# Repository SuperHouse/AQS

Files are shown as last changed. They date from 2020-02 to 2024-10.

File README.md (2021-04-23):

Air Quality Sensor
==================

Build a DIY Air Quality Sensor to monitor the condition of the air in
your home or office, with options for measuring airborne particulate
matter, temperature, humidity, barometric pressure, and volatile
organic compounds.

This project is documented in an ongoing video series on SuperHouse:

* [DIY Air Quality Sensor, part 1: “Basic” version](https://www.superhouse.tv/38-diy-air-quality-sensor-part-1-basic-model/)
* [DIY Air Quality Sensor, part 2: “Display” version](https://www.superhouse.tv/39-diy-air-quality-sensor-part-2-display-version/)
* [DIY Air Quality Sensor, part 3: source code walkthrough](https://www.superhouse.tv/40-diy-air-quality-sensor-part-3-software/)

There are 3 different versions of this project:

 * The "Basic" version which requires only a Wemos D1 Mini and a
   Plantower PMS5003 laser particulate matter sensor.
 * The "Display" version which adds a 128x32 OLED display to the
   Basic version.
 * The "Pro" version which is based on a fully custom PCB with an ESP32
   MCU, a Plantower PMS7003 sensor, a Bosch BME680 environmental
   sensor, and a 240x240 colour LCD.

Measurements can be shown locally if a display is fitted, and can also
be reported to MQTT over WiFi so that data can be accessed by a home
automation system or external database.

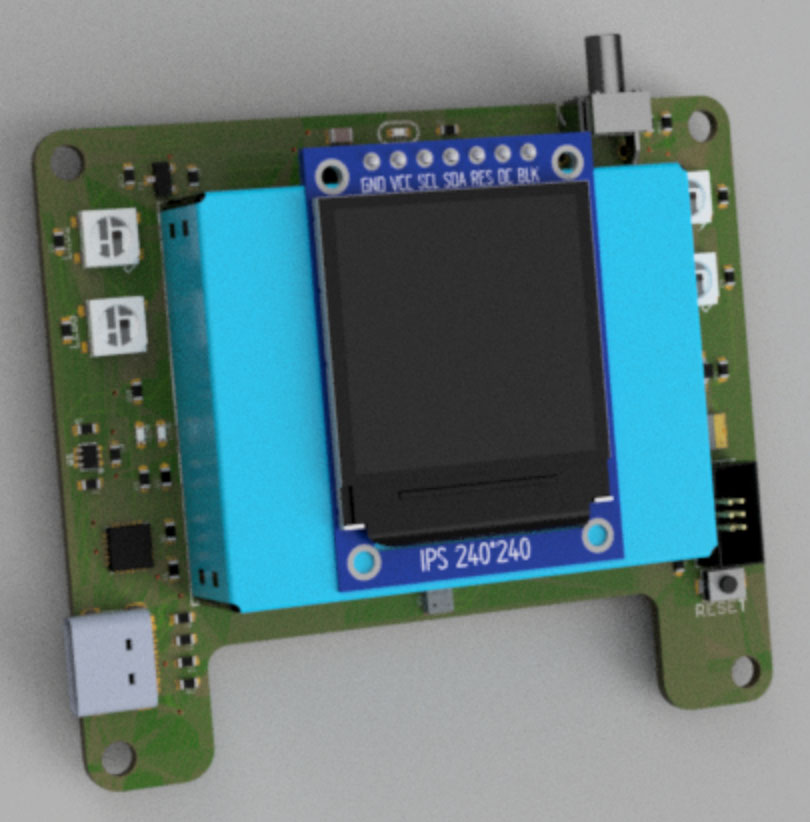
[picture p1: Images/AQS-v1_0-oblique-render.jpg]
Air Quality Sensor PCB


"Basic" and "Display" version features:

 * PMS5003 particulate matter sensor
 * ESP8266 processor with WiFi
 * Micro-USB connection for power or reflashing
 * 3D-printable case

"Pro" version features:

 * PMS7003 particulate matter sensor
 * BME680 VOC sensor
 * ESP32 processor with WiFi and Bluetooth
 * USB-C connection for power or reflashing
 * 3D-printable case

More information is available at:

  https://www.superhouse.tv/aqs

Hardware
--------
The "Hardware" directory contains the PCB design as an EAGLE project.

Firmware
--------
The "Firmware" directory contains example firmware as an Arduino
project.

Enclosure
---------
The "Enclosure" directory contains STLs for a case that can be
3D-printed.

The two halves of the case should be printed with the flat face down to
the printer bed.

The case can be held shut by M3 bolts.

Credits
-------
 * Jonathan Oxer <jon@oxer.com.au>

License
-------
Copyright 2020-2021 SuperHouse Automation Pty Ltd  www.superhouse.tv  

The hardware portion of this project is licensed under the TAPR Open
Hardware License (www.tapr.org/OHL). The "license" folder within this
repository contains a copy of this license in plain text format.

The software portion of this project is licensed under the Simplified
BSD License. The "licence" folder within this project contains a
copy of this license in plain text format.

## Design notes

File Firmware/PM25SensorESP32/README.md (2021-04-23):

"Pro" version Particulate Matter Sensor firmware
=================================================

NOTE: This version of the firmware is for the "Pro" version of the
SuperHouse Air Quality Sensor project. It does not work on the "Basic"
and "Display" version of the project.

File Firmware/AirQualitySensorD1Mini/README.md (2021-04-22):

"Basic" & "Display" Air Quality Sensor firmware for D1 Mini
============================================================

NOTE: This version of the firmware is for the "Basic" and "Display"
versions of the SuperHouse Air Quality Sensor project. It does not
work on the "Pro" version of the project.

Read from a Plantower PMS5003 particulate matter sensor using a Wemos D1
Mini (or other ESP8266-based board) and report the values to an MQTT
broker and show them on a 128x32 OLED display.

The mode button and OLED are optional. You can build this device with
nothing but a PMS5003 and a D1 Mini, and it will work just fine.

On startup, the device reads its own ESP8266 chip ID and uses this as the
basis for its MQTT topics and client ID, to ensure that they will be
unique for each device.

It displays this ID on the OLED display so you can read it off the
display if you have one installed. In case you don't, it also reports
the ID via the serial console at 9600bps, and publishes a startup
message to the topic "events" including its own ID. You can watch that
topic while the device is booting to see what ID it reports.

This ID is then used to generate topics for it to report its readings.
The topics take the following form, with its unique ID substituted:

 * tele/d9616f/PM1
 * tele/d9616f/PM2.5
 * tele/d9616f/PM10
 * tele/d9616f/PPD0.3
 * tele/d9616f/PPD0.5
 * ...etc

The values are also reported in a combined format as JSON, in the same
structure used by Tasmota, at a topic similar to:

 * tele/d9616f/SENSOR

If you install the OLED and the mode button, you can use the button to
toggle the display between different screens. The first screen shows the
most recent readings in micrograms per cubic meter. The second screen
shows the most recent readings in particles per deciliter. The third
screen shows network information including the MQTT ID, IP address, WiFi
SSID, WiFi connection status, and uptime.

Dependencies
------------

These dependencies can all be fulfilled in the Arduino IDE using
"Sketch -> Include Library -> Manage Libraries..."

 * GFX library by Adafruit https://github.com/adafruit/Adafruit-GFX-Library
 * SSD1306 library by Adafruit https://github.com/adafruit/Adafruit_SSD1306
 * PubSubClient library by Nick O'Leary https://pubsubclient.knolleary.net

It also uses a version of Mariusz Kacki's "PMS" library that was forked by
SwapBap. You do not need to install this library separately, because it's
included in the project.

Connections
-----------

For particulate matter sensor:
 * PMS5003 pin 1 (VCC) to D1 Mini "5V" pin
 * PMS5003 pin 2 (GND) to D1 Mini "GND" pin
 * PMS5003 pin 4 (RX) to D1 Mini "D8" pin
 * PMS5003 pin 5 (TX) to D1 Mini "D4" pin

For mode button:
 * Button connected between D1 Mini "D7" pin (GPIO13) and GND

For 128x32 I2C OLED:
 * OLED VCC to D1 Mini 3.3V
 * OLED GND to D1 Mini GND
 * OLED SCL to D1 Mini "D1" pin
 * OLED SDA to D1 Mini "D2" pin

To do
-----

 * 

Credits
-------

Written by Jonathan Oxer for www.superhouse.tv  
https://github.com/superhouse/AQS

Inspired by https://github.com/SwapBap/WemosDustSensor

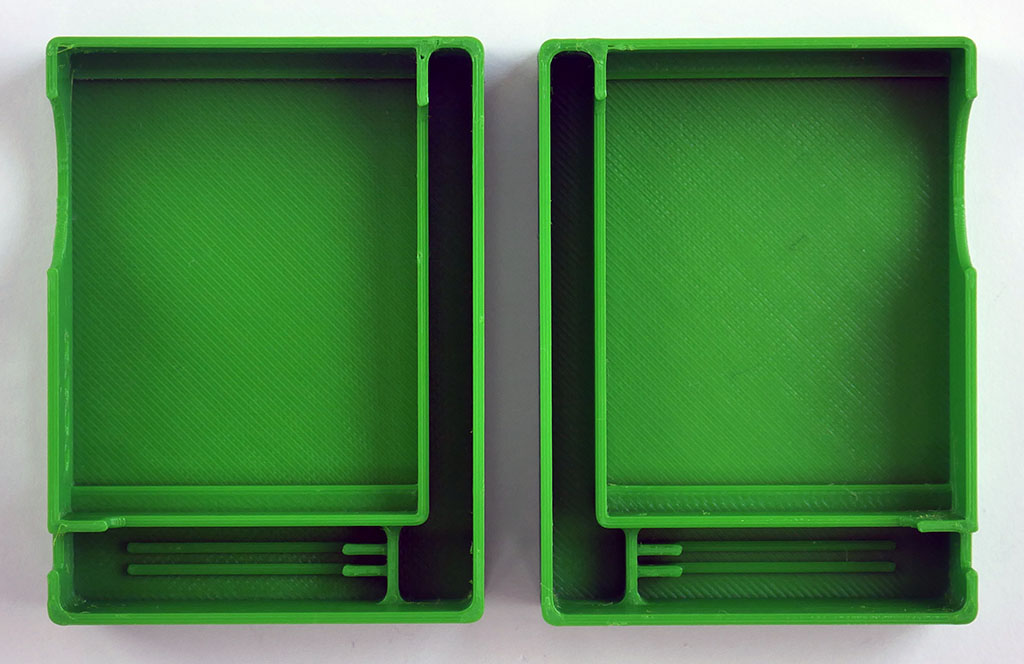
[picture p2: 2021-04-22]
Images/AQSBCASE-v1_0-green-top.jpg

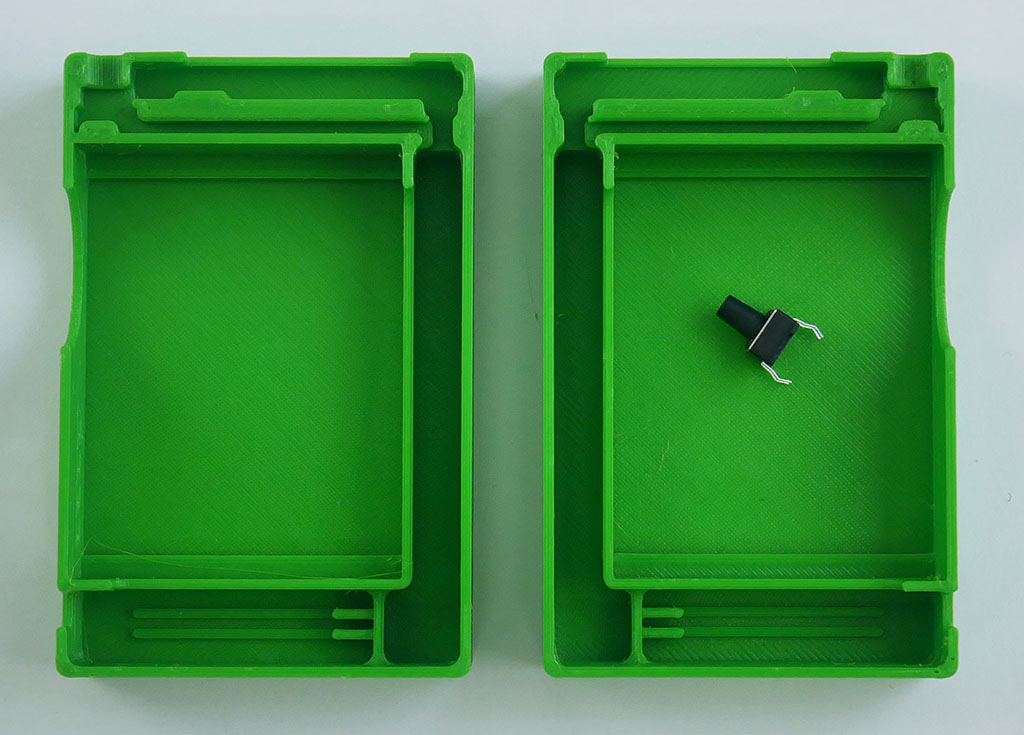
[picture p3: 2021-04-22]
Images/AQSDCASE-v1_0-green-top.jpg

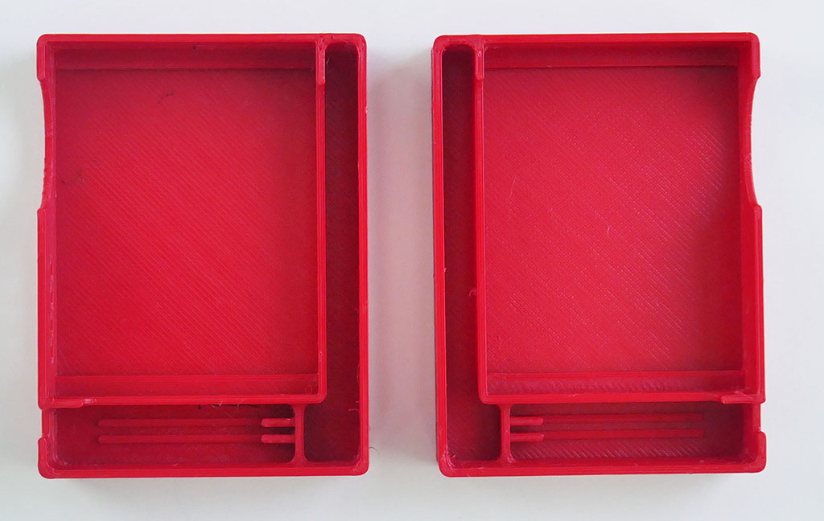
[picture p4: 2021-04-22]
Images/AQSBCASE-v1_0-red-top.jpg

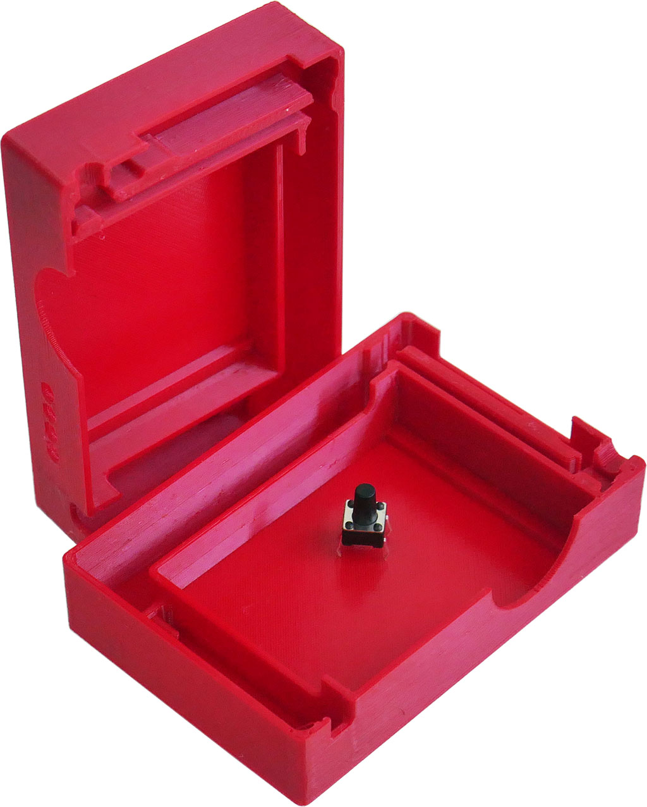
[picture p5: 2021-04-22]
Images/AQSDCASE-v1_0-red-oblique.jpg

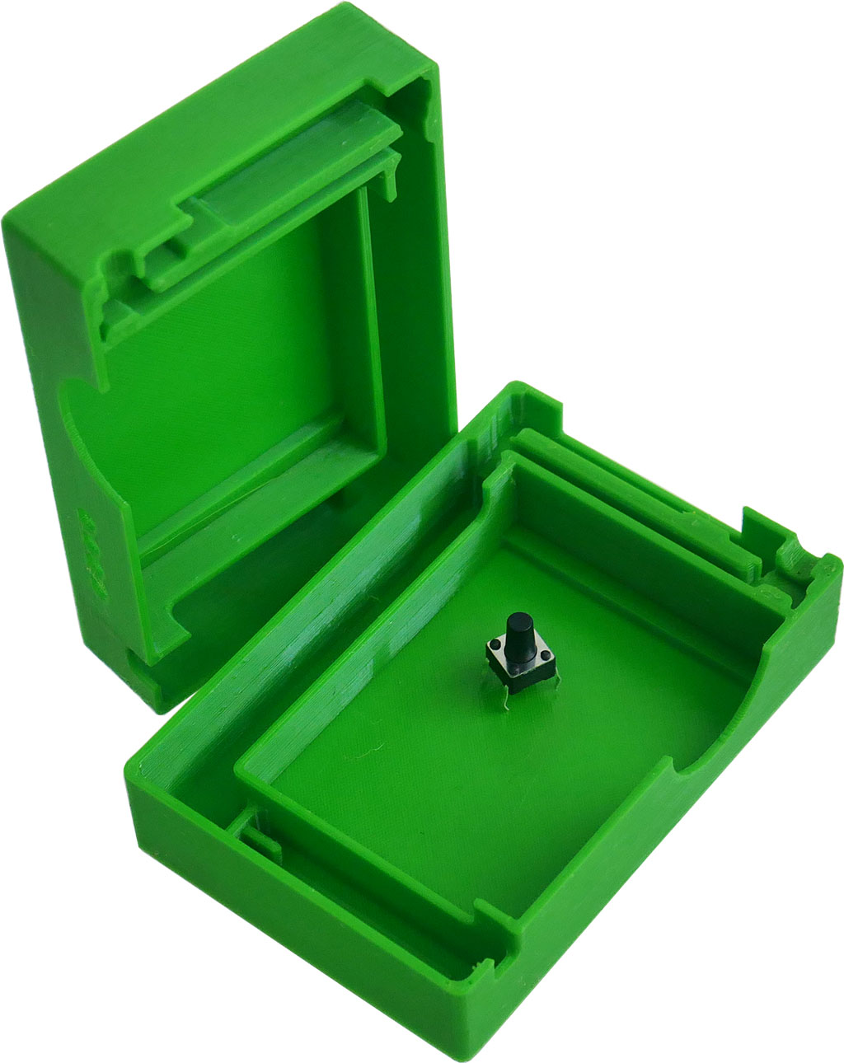
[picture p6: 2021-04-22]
Images/AQSDCASE-v1_0-green-oblique.jpg

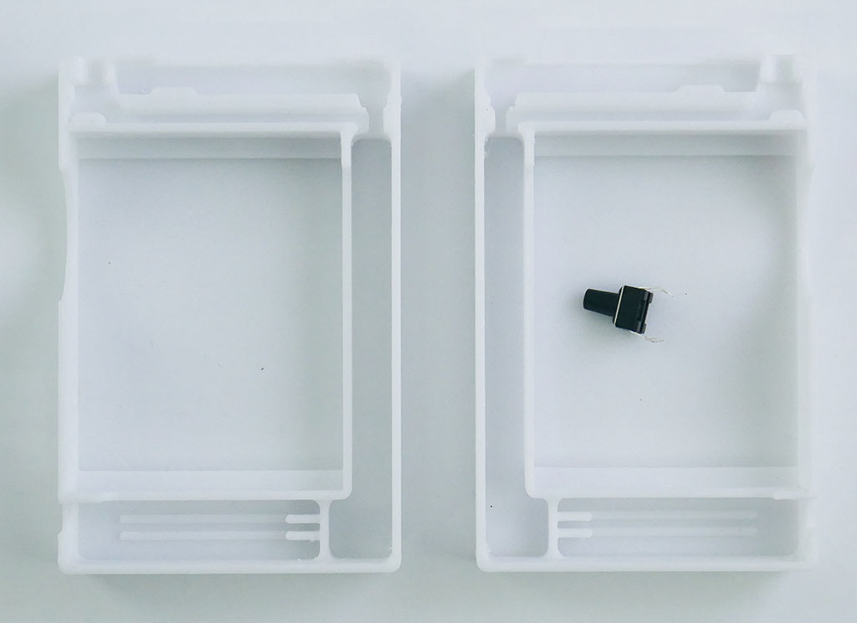
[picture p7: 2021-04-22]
Images/AQSDCASE-v1_0-white-top.jpg

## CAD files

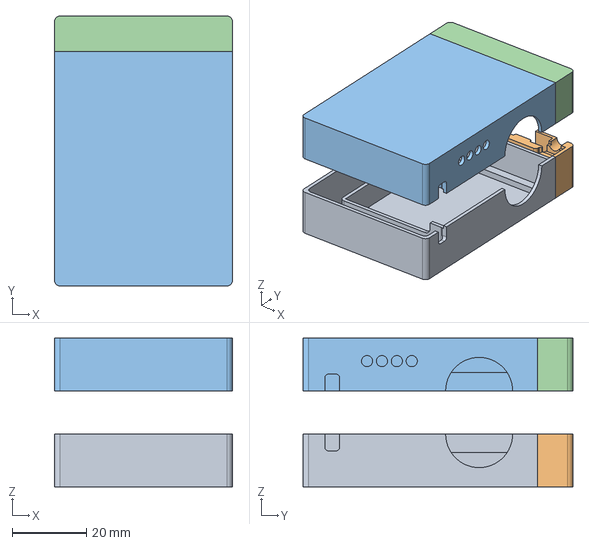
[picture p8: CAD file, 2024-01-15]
Enclosure/AQS-Display-Case-v16.step
47.8 x 72.5 x 40.0 mm

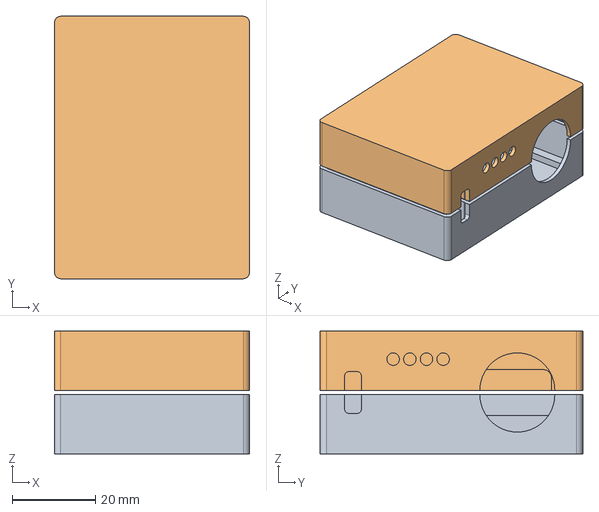
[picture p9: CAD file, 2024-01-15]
Enclosure/AQS-Simple-Case-v5.step
46.8 x 63.0 x 29.4 mm

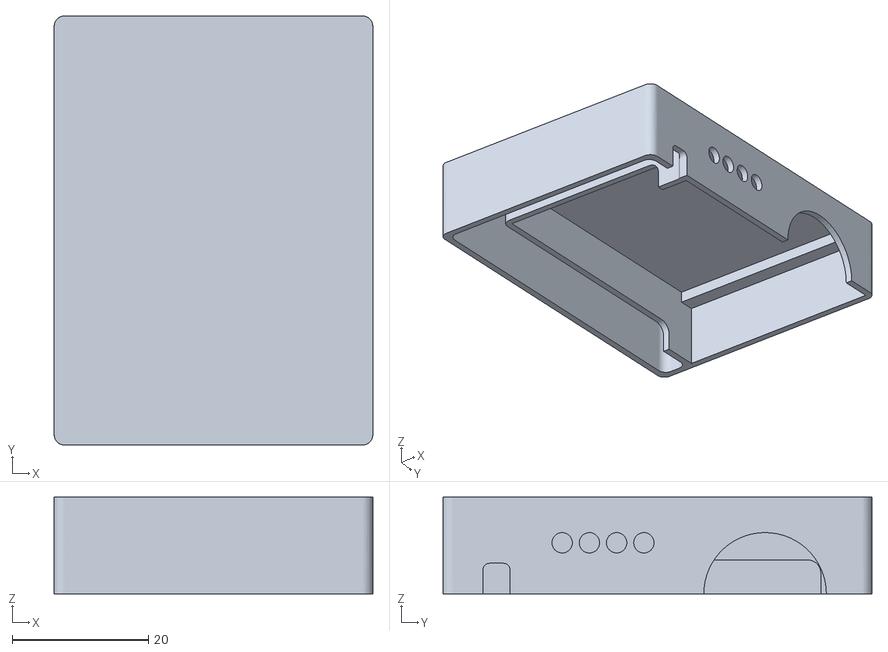
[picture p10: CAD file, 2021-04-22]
Enclosure/AQS-Basic-Case-1_2mm-v1-top.stl
46.8 x 63.0 x 14.2

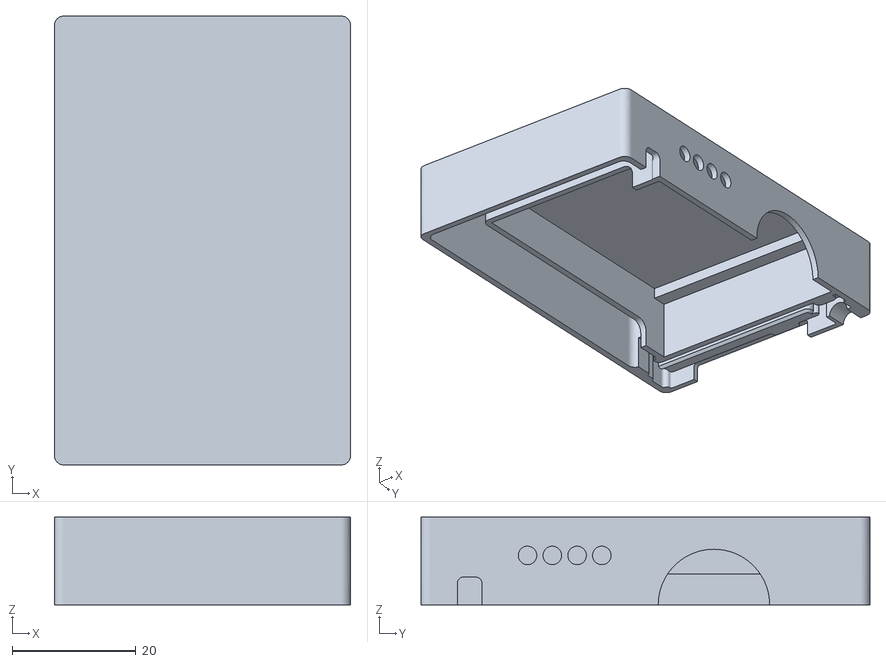
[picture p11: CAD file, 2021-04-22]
Enclosure/AQS-Display-Case-1_2mm-v1-top.stl
47.8 x 72.5 x 14.2

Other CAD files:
Enclosure/AQS-Basic-Case-1_6mm-v1-top.stl
Enclosure/AQS-Display-Case-1_6mm-v1-bottom.stl
Enclosure/AQS-Display-Case-1_6mm-v1-top.stl
Enclosure/AQS-Basic-Case-1_6mm-v1-bottom.stl
Enclosure/AQS-Display-Case-1_2mm-v1-bottom.stl
Enclosure/AQS-Basic-Case-1_2mm-v1-bottom.stl
Enclosure/AQS-Simple-Case-v5.f3d

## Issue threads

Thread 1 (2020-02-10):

The URL specified for more information returns a 404

KathyReid, 2020-02-10:
Hi Jon,
This project looks super exciting, and I'd really like to buy one of these boards from you.
The page http://www.superhouse.tv/aqs is returning a 404

```
kathyreid@kathyreid-zenbook-ux533fd:~$ wget http://www.superhouse.tv/aqs
--2020-02-11 10:33:06--  http://www.superhouse.tv/aqs
Resolving www.superhouse.tv (www.superhouse.tv)... 23.239.0.84
Connecting to www.superhouse.tv (www.superhouse.tv)|23.239.0.84|:80... connected.
HTTP request sent, awaiting response... 301 Moved Permanently
Location: https://www.superhouse.tv/aqs [following]
--2020-02-11 10:33:06--  https://www.superhouse.tv/aqs
Connecting to www.superhouse.tv (www.superhouse.tv)|23.239.0.84|:443... connected.
HTTP request sent, awaiting response... 404 Not Found
2020-02-11 10:33:09 ERROR 404: Not Found.
```

Kind regards,
Kathy

jonoxer, 2020-02-11:
Thanks Kathy! I haven't created the page yet, but I needed to get something onto the silkscreen before I ordered the PCBs. I'll make it soon :-)

KathyReid, 2020-02-11:
Awesomeness <3

jonoxer, 2020-02-11:
Fixed :-)

Closed 2020-02-11.

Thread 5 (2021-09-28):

Mosquito broker issues failures to connect

swissMack, 2021-09-28:
1632836398: New connection from 192.168.1.73 on port 1883.
1632836398: Socket error on client <unknown>, disconnecting.

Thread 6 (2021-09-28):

PMS Tx PIN

swissMack, 2021-09-28:
should this be D6 or D8?
code says D8, website says D6
either way I fail to maintain a connection to my mosquito broker which prevents the code from running as standalone

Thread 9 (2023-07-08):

What happened to parts 4 and 6?

bwims, 2023-07-08:
Hi, what happened to:

Part 4: Recording and reporting Air Quality Sensor data (coming soon)
Part 5: DIY Air Quality Sensor “Pro” version (coming soon)

Coming soon?  It's been 3 years!  :-)

bwims, 2023-09-16:
Bump!

austinscreations, 2023-09-18:
this has been discussed a few times in various livestreams over the years.

1) backend stuff has changed quite a bit over the years that would require a full re-shoot of content to make it useful / relevant
2) life events have happened
3) professional paid work takes precedence. and jons mostly a one man shop with occasional help from his son.

bwims, 2023-09-18:
Fair enough.  In that case, how much effort would there be in coming clean and editing the appropriate information into the blog entries?  I.E. don't raise expectations unnecessarily.  Say.  "Nope.  Forget about any future development. "

Thankfully, ESPhome caters for this device and provides all the extras required.

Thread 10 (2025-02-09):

Stuck on preparing sensors

cruisermattew, 2025-02-09:
The code compiles and is successfully uploaded to the D1 Mini, the screen cycles from the starting menu where the device ID is stated but can't progress past the "preparing sensor and waiting for data" screen. I have used this sensor using Tasmota and received readings so I'm assuming it is an issue with the connection between the sensor and the screen. I am not very knowledgeable in this area so any help would be appreciated.

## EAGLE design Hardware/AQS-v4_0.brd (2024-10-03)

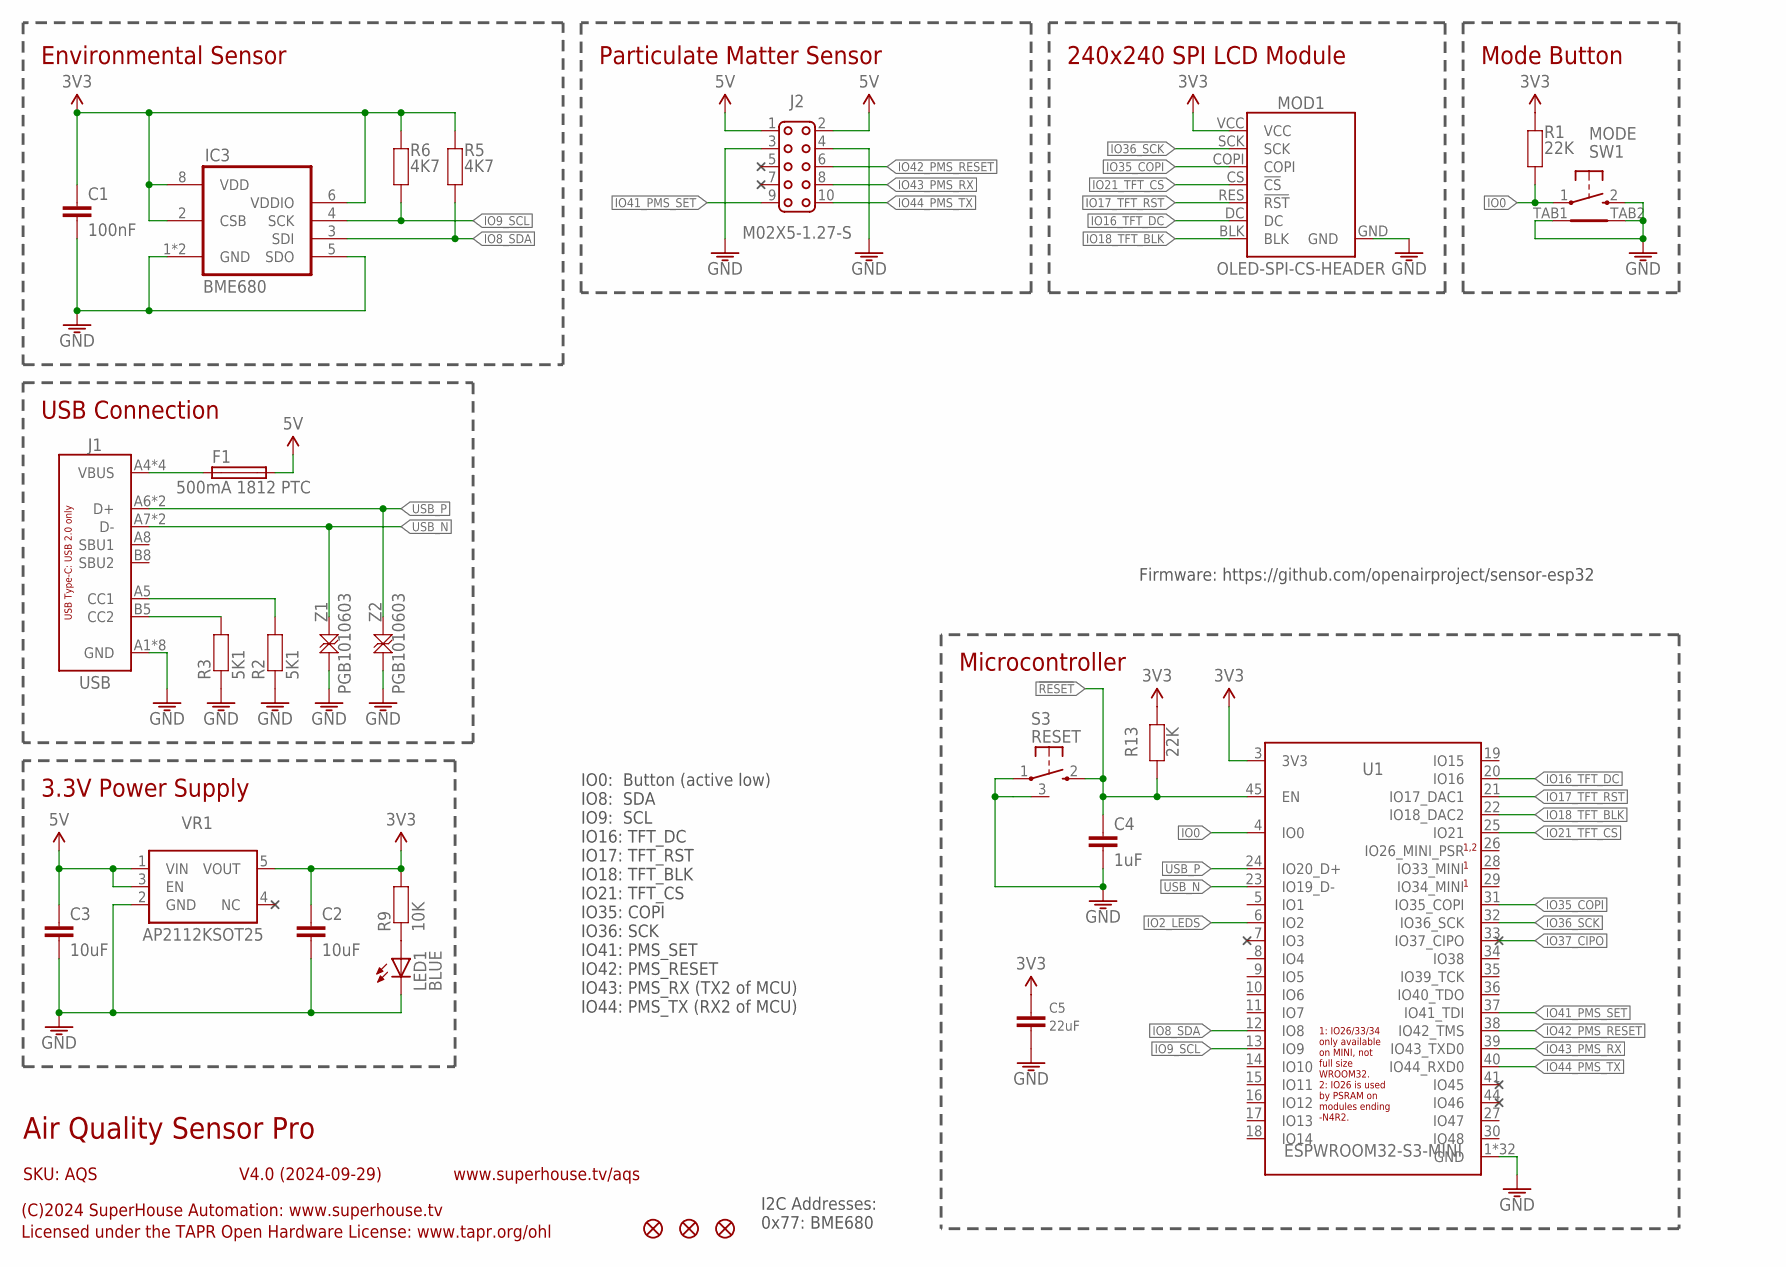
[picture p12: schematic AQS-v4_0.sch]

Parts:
C1: 100nF; C0603
C2, C3: 10uF; C0805
C4: 1uF; C0603
C5: 22uF; C0805
F1: 500mA 1812 PTC; 1206
IC3: BME680
J1: USB; USB-C-VERT
J2: M02X5-1.27-S; 2X05-1.27-S
LED1: BLUE; LED-0603
MOD1: OLED-SPI-CS-HEADER; OLED-240X240-1.54-HEADER
R1, R13: 22K; R0603
R2, R3: 5K1; R0603
R5, R6: 4K7; R0603
R9: 10K; R0603
S3: RESET; TACT-VERT-1TAB
SW1: MODE; TYCO-FSMRAJ
U1: ESPWROOM32-S3-MINI; ESP32-S3-MINI
U$23, U$24, U$25: FIDUCIAL1X2; FIDUCIAL-1X2
VR1: AP2112KSOT25; SOT23-5
Z1, Z2: PGB1010603; TVS0603

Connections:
3.3V: C1.1, C2.1, C5.1, IC3.2 (CSB), IC3.6 (VDDIO), IC3.8 (VDD), MOD1.VCC, R1.2, R5.2, R6.2, R9.2, R13.1, U1.3 (3V3), VR1.5 (VOUT)
5V: C3.1, F1.2, J2.1, J2.2, VR1.1 (VIN), VR1.3 (EN)
!RESET: C4.1, R13.2, S3.2, U1.45 (EN)
GND: C1.2, C2.2, C3.2, C4.2, C5.2, IC3.1 (GND), IC3.5 (SDO), IC3.7 (GND), J1.A1 (GND), J1.A12 (GND), J1.B1 (GND), J1.B12 (GND), J1.FIX1 (GND), J1.FIX2 (GND), J1.FIX3 (GND), J1.FIX4 (GND), J2.3, J2.4, LED1.C, MOD1.GND, R2.1, R3.1, S3.1, S3.3, SW1.2, SW1.TAB1, SW1.TAB2, U1.1 (GND), U1.2 (GND), U1.42 (GND), U1.43 (GND), U1.46 (GND), U1.47 (GND), U1.48 (GND), U1.49 (GND), U1.50 (GND), U1.51 (GND), U1.52 (GND), U1.53 (GND), U1.54 (GND), U1.55 (GND), U1.56 (GND), U1.57 (GND), U1.58 (GND), U1.59 (GND), U1.60 (GND), U1.61 (GND), U1.62 (GND), U1.63 (GND), U1.64 (GND), U1.65 (GND), U1.G1 (GND), U1.G2 (GND), U1.G3 (GND), U1.G4 (GND), U1.G6 (GND), U1.G7 (GND), U1.G8 (GND), U1.G9 (GND), VR1.2 (GND), Z1.1, Z2.1
IO0: R1.1, SW1.1, U1.4 (IO0)
IO2_LEDS: U1.6 (IO2)
IO8_SDA: IC3.3 (SDI), R5.1, U1.12 (IO8)
IO9_SCL: IC3.4 (SCK), R6.1, U1.13 (IO9)
IO16_TFT_DC: MOD1.DC, U1.20 (IO16)
IO17_TFT_RST: MOD1.RES (!RST), U1.21 (IO17_DAC1)
IO18_TFT_BLK: MOD1.BLK, U1.22 (IO18_DAC2)
IO21_TFT_CS: MOD1.CS (!CS), U1.25 (IO21)
IO35_COPI: MOD1.COPI, U1.31 (IO35_COPI)
IO36_SCK: MOD1.SCK, U1.32 (IO36_SCK)
IO37_CIPO: U1.33 (IO37_CIPO)
IO41_PMS_SET: J2.9, U1.37 (IO41_TDI)
IO42_PMS_RESET: J2.6, U1.38 (IO42_TMS)
IO43_PMS_RX: J2.8, U1.39 (IO43_TXD0)
IO44_PMS_TX: J2.10, U1.40 (IO44_RXD0)
IO46: U1.44 (IO46)
unnamed: LED1.A, R9.1
unnamed: F1.1, J1.A4 (VBUS), J1.A9 (VBUS), J1.B4 (VBUS), J1.B9 (VBUS)
unnamed: J1.B5 (CC2), R3.2
unnamed: J1.A5 (CC1), R2.2
USB_N: J1.A7 (D-), J1.B7 (D-), U1.23 (IO19_D-), Z1.2
USB_P: J1.A6 (D+), J1.B6 (D+), U1.24 (IO20_D+), Z2.2

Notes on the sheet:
V4.0 (2024-09-29)
USB Connection
3.3V Power Supply
Microcontroller
I2C Addresses: 0x77: BME680
IO0: Button (active low) IO8: SDA IO9: SCL IO16: TFT_DC IO17: TFT_RST IO18: TFT_BLK IO21: TFT_CS IO35: COPI IO36: SCK IO41: PMS_SET IO42: PMS_RESET IO43: PMS_RX (TX2 of MCU) IO44: PMS_TX (RX2 of MCU)
Air Quality Sensor Pro
SKU: AQS
(C)2024 SuperHouse Automation: www.superhouse.tv
Licensed under the TAPR Open Hardware License: www.tapr.org/ohl
www.superhouse.tv/aqs
Environmental Sensor
240x240 SPI LCD Module
Particulate Matter Sensor
Mode Button
Firmware: https://github.com/openairproject/sensor-esp32

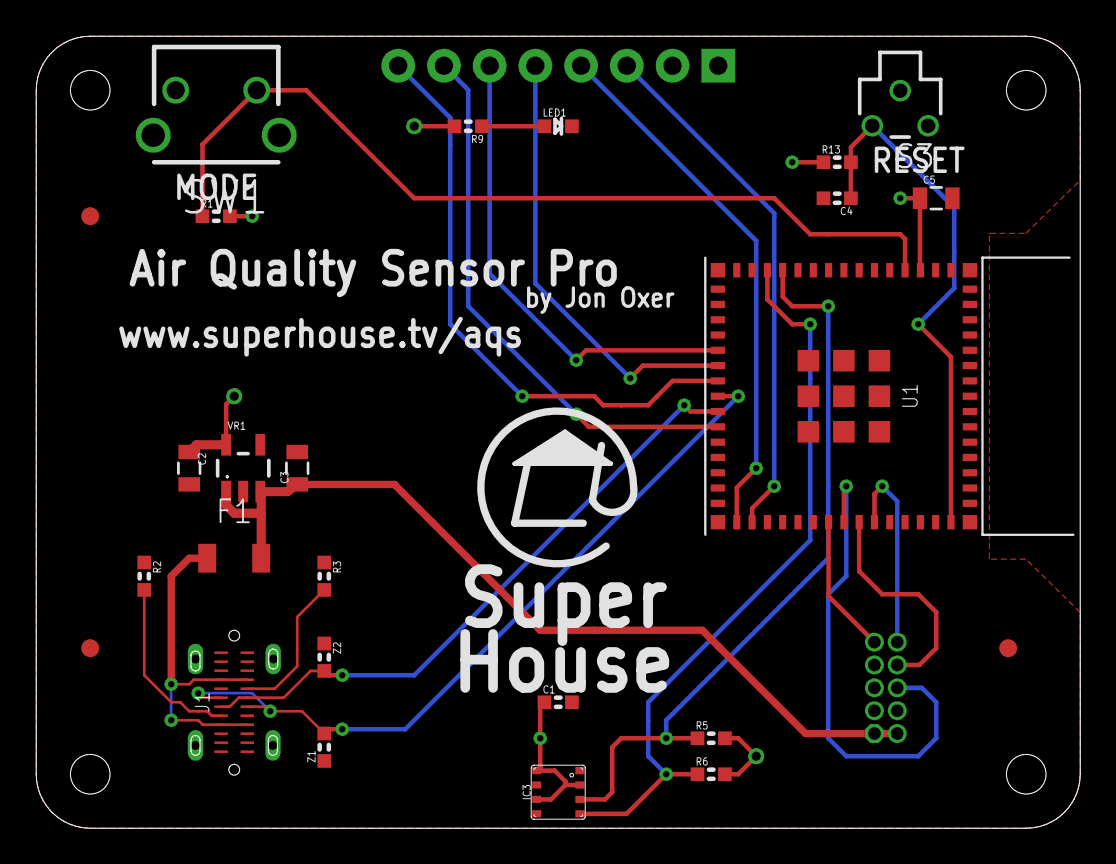
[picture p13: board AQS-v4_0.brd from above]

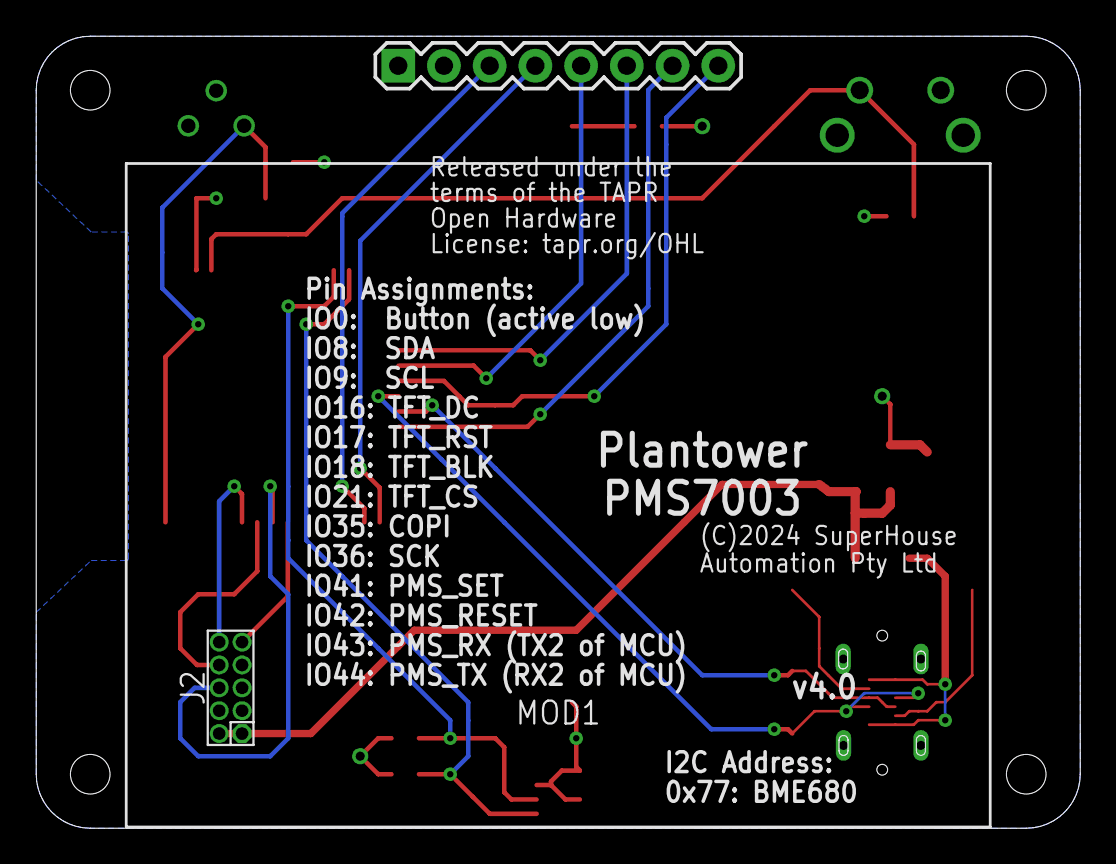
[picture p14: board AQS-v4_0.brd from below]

Board: 2 copper layers, 58.0 x 44.0 mm, 27 parts (2 on the bottom side), 23 nets.

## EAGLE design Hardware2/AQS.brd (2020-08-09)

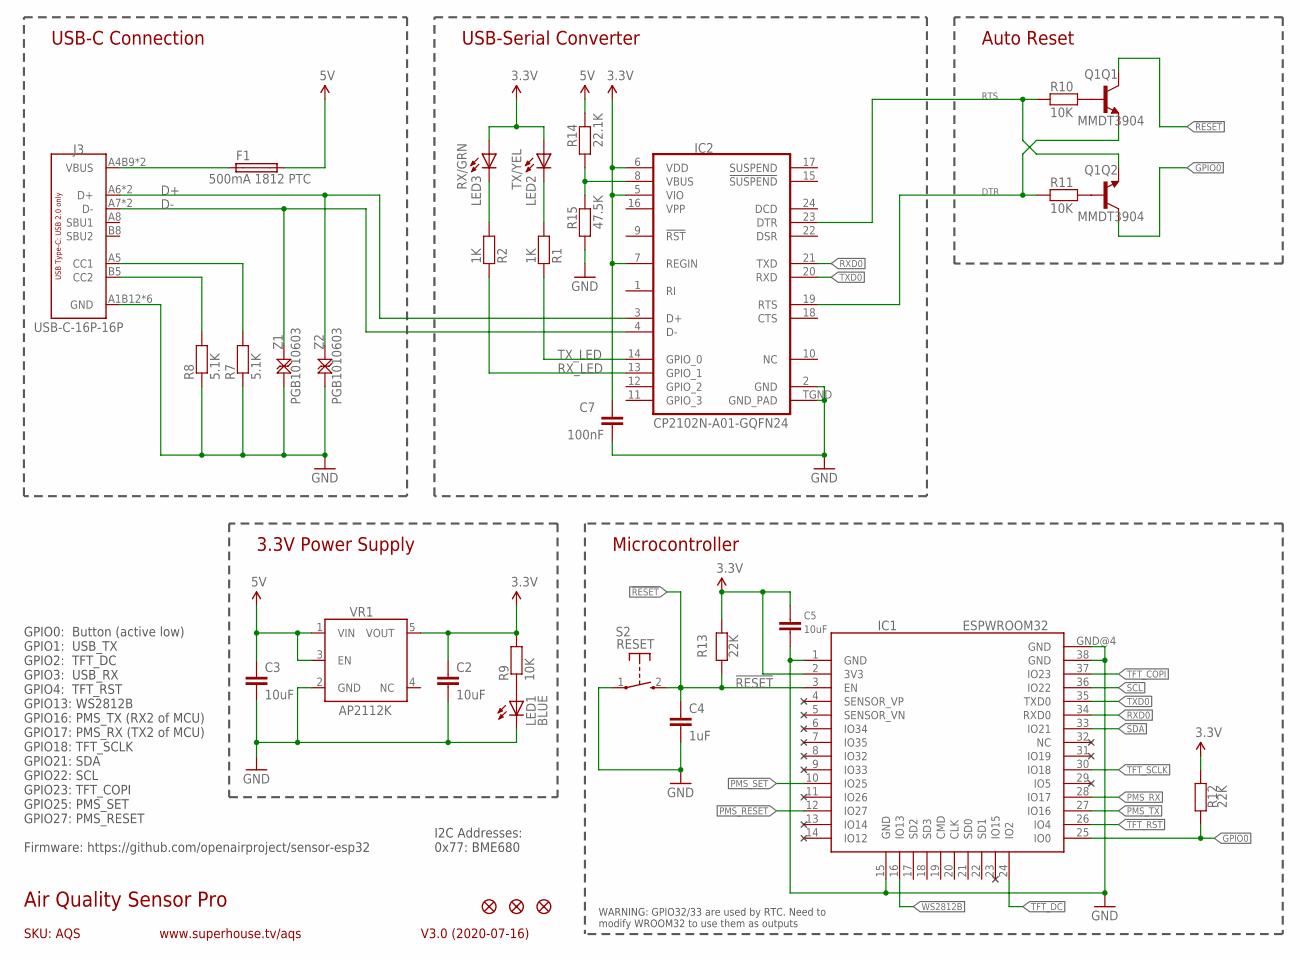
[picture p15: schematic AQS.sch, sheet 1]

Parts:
C2, C3, C5: 10uF; C0805
C4: 1uF; C0603
C7: 100nF; C0603
F1: 500mA 1812 PTC; 1812
IC1: ESPWROOM32
IC2: CP2102N-A01-GQFN24; QFN-24
J3: USB-C-16P-16P; USB-C-16P
LED1: BLUE; LED-0603
LED2: TX/YEL; LED-0603
LED3: RX/GRN; LED-0603
Q1: MMDT3904; SOT-363
R1, R2: 1K; R0603
R7, R8: 5.1K; R0603
R9, R10, R11: 10K; R0603
R12, R13: 22K; R0603
R14: 22.1K; R0603
R15: 47.5K; R0603
S2: RESET; TACTILE_SMT_3X4X2
U$23, U$24, U$25: FIDUCIAL1X2; FIDUCIAL-1X2
VR1: AP2112KSOT25; SOT23-5
Z1, Z2: PGB1010603; TVS0603

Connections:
3.3V: C2.1, C5.1, C7.1, IC1.2 (3V3), IC2.5 (VIO), IC2.6 (VDD), IC2.7 (REGIN), LED2.A, LED3.A, R9.2, R12.1, R13.1, VR1.5 (VOUT); also elsewhere on the board
5V: C3.1, F1.2, R14.2, VR1.1 (VIN), VR1.3 (EN); also elsewhere on the board
!RESET: C4.1, IC1.3 (EN), Q1.3 (C), R13.2, S2.2 (S)
D+: IC2.3 (D+), J3.A6 (D+), J3.B6 (D+), Z2.2
D-: IC2.4 (D-), J3.A7 (D-), J3.B7 (D-), Z1.2
DTR: IC2.23 (DTR), Q1.1 (E), R10.1
GND: C2.2, C3.2, C4.2, C5.2, C7.2, IC1.1 (GND), IC1.15 (GND), IC1.38 (GND), IC1.GND@4 (GND), IC2.2 (GND), IC2.TGND (GND_PAD), J3.A1B12 (GND), J3.A12B1 (GND), J3.FIX1 (GND), J3.FIX2 (GND), J3.FIX3 (GND), J3.FIX4 (GND), LED1.C, R7.1, R8.1, R15.1, S2.1, VR1.2 (GND), Z1.1, Z2.1; also elsewhere on the board
GPIO0: IC1.25 (IO0), Q1.6 (C), R12.2; also elsewhere on the board
unnamed: LED1.A, R9.1
unnamed: LED3.C, R2.2
unnamed: Q1.5 (B), R10.2
unnamed: Q1.2 (B), R11.2
unnamed: J3.B5 (CC2), R8.2
unnamed: J3.A5 (CC1), R7.2
unnamed: LED2.C, R1.2
unnamed: IC2.8 (VBUS), R14.1, R15.2
PMS_RESET: IC1.12 (IO27); also elsewhere on the board
PMS_RX: IC1.28 (IO17); also elsewhere on the board
PMS_SET: IC1.10 (IO25); also elsewhere on the board
PMS_TX: IC1.27 (IO16); also elsewhere on the board
RTS: IC2.19 (RTS), Q1.4 (E), R11.1
RXD0: IC1.34 (RXD0), IC2.21 (TXD)
RX_LED: IC2.13 (GPIO_1), R2.1
SCL: IC1.36 (IO22); also elsewhere on the board
SDA: IC1.33 (IO21); also elsewhere on the board
TFT_COPI: IC1.37 (IO23); also elsewhere on the board
TFT_DC: IC1.24 (IO2); also elsewhere on the board
TFT_RST: IC1.26 (IO4); also elsewhere on the board
TFT_SCLK: IC1.30 (IO18); also elsewhere on the board
TXD0: IC1.35 (TXD0), IC2.20 (RXD)
TX_LED: IC2.14 (GPIO_0), R1.1
VIN: F1.1, J3.A4B9 (VBUS), J3.A9B4 (VBUS)
WS2812B: IC1.16 (IO13)

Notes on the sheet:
SKU: AQS
Air Quality Sensor Pro
V3.0 (2020-07-16)
www.superhouse.tv/aqs
USB-C Connection
USB-Serial Converter
Auto Reset
3.3V Power Supply
Microcontroller
WARNING: GPIO32/33 are used by RTC. Need to modify WROOM32 to use them as outputs
I2C Addresses: 0x77: BME680
GPIO0: Button (active low) GPIO1: USB_TX GPIO2: TFT_DC GPIO3: USB_RX GPIO4: TFT_RST GPIO13: WS2812B GPIO16: PMS_TX (RX2 of MCU) GPIO17: PMS_RX (TX2 of MCU) GPIO18: TFT_SCLK GPIO21: SDA GPIO22: SCL GPIO23: TFT_COPI GPIO25: PMS_SET GPIO27: PMS_RESET Firmware: https://github.com/openairproject/sensor-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

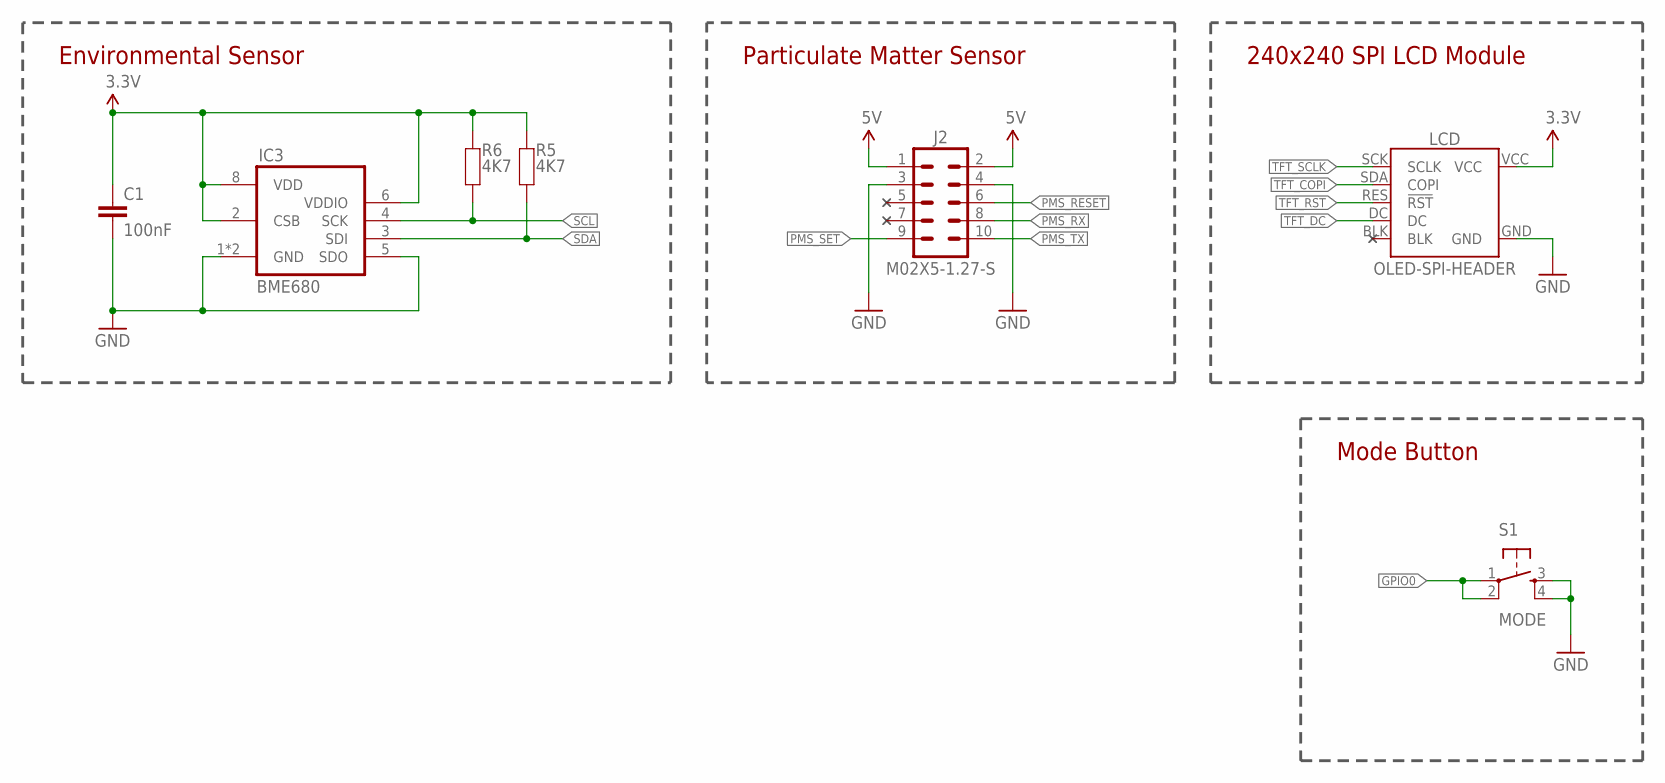
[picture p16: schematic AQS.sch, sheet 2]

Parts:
C1: 100nF; C0603
IC3: BME680
J2: M02X5-1.27-S; 2X05-1.27-S
LCD: OLED-SPI-HEADER; OLED-240X240-1.3-HEADER
R5, R6: 4K7; R0603
S1: MODE; TACTILE-PTH-4.5MM

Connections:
3.3V: C1.1, IC3.2 (CSB), IC3.6 (VDDIO), IC3.8 (VDD), LCD.VCC, R5.2, R6.2; also elsewhere on the board
5V: J2.1, J2.2; also elsewhere on the board
GND: C1.2, IC3.1 (GND), IC3.5 (SDO), IC3.7 (GND), J2.3, J2.4, LCD.GND, S1.3, S1.4; also elsewhere on the board
GPIO0: S1.1, S1.2; also elsewhere on the board
PMS_RESET: J2.6; also elsewhere on the board
PMS_RX: J2.8; also elsewhere on the board
PMS_SET: J2.9; also elsewhere on the board
PMS_TX: J2.10; also elsewhere on the board
SCL: IC3.4 (SCK), R6.1; also elsewhere on the board
SDA: IC3.3 (SDI), R5.1; also elsewhere on the board
TFT_COPI: LCD.SDA (COPI); also elsewhere on the board
TFT_DC: LCD.DC; also elsewhere on the board
TFT_RST: LCD.RES (!RST); also elsewhere on the board
TFT_SCLK: LCD.SCK (SCLK); also elsewhere on the board

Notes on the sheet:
Environmental Sensor
240x240 SPI LCD Module
Particulate Matter Sensor
Mode Button

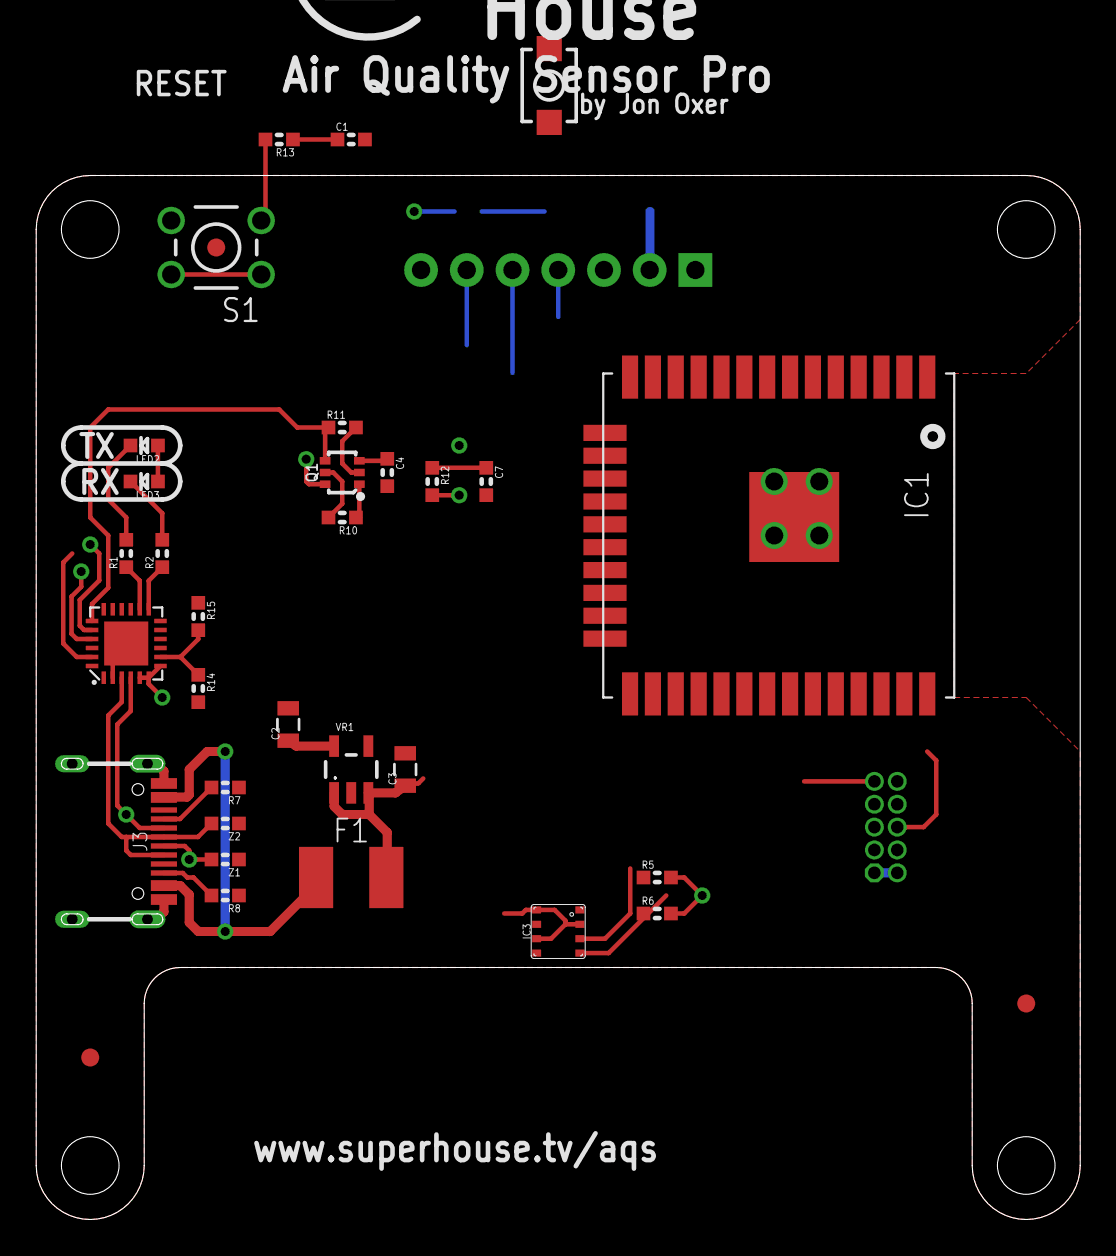
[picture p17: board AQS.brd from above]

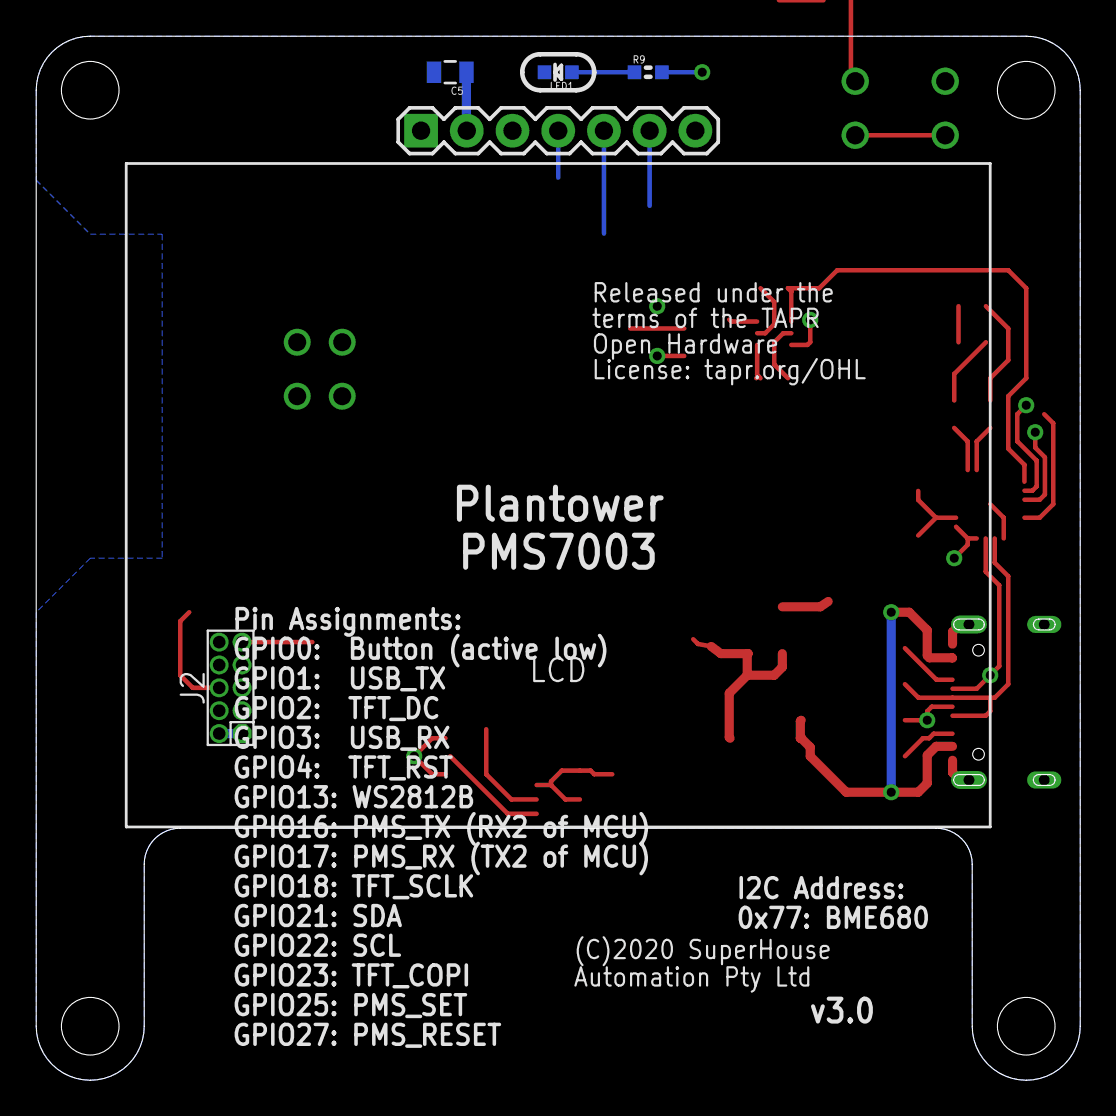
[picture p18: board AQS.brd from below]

Board: 2 copper layers, 58.0 x 58.0 mm, 38 parts (5 on the bottom side), 32 nets.

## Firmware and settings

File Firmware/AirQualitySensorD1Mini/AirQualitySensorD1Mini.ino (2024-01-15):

/**
  Particulate matter sensor firmware for D1 Mini (ESP8266) and PMS5003

  Read from a Plantower PMS5003 particulate matter sensor using a Wemos D1
  Mini (or other ESP8266-based board) and report the values to an MQTT
  broker and to the serial console. Also optionally show them on a 128x32
  I2C OLED display, with a mode button to change between display modes.

  External dependencies. Install using the Arduino library manager:
     "Adafruit GFX Library" by Adafruit
     "Adafruit SSD1306" by Adafruit
     "PubSubClient" by Nick O'Leary

  Bundled dependencies. No need to install separately:
     "PMS Library" by Mariusz Kacki, forked by SwapBap

  Written by Jonathan Oxer for www.superhouse.tv
    https://github.com/superhouse/AirQualitySensorD1Mini

  Inspired by https://github.com/SwapBap/WemosDustSensor/

  Copyright 2020 SuperHouse Automation Pty Ltd www.superhouse.tv
*/
#define VERSION "2.6"
/*--------------------------- Configuration ------------------------------*/
// Configuration should be done in the included file:
#include "config.h"

/*--------------------------- Libraries ----------------------------------*/
#include <Wire.h>                     // For I2C
#include <SoftwareSerial.h>           // Allows PMS to avoid the USB serial port
#include <Adafruit_GFX.h>             // For OLED
#include <Adafruit_SSD1306.h>         // For OLED
#include <ESP8266WiFi.h>              // ESP8266 WiFi driver
#include <PubSubClient.h>             // Required for MQTT
#include "PMS.h"                      // Particulate Matter Sensor driver (embedded)

/*--------------------------- Global Variables ---------------------------*/
// Particulate matter sensor
#define   PMS_STATE_ASLEEP        0   // Low power mode, laser and fan off
#define   PMS_STATE_WAKING_UP     1   // Laser and fan on, not ready yet
#define   PMS_STATE_READY         2   // Warmed up, ready to give data
uint8_t   g_pms_state           = PMS_STATE_WAKING_UP;
uint32_t  g_pms_state_start     = 0;  // Timestamp when PMS state last changed
uint8_t   g_pms_ae_readings_taken  = false;  // true/false: whether any readings have been taken
uint8_t   g_pms_ppd_readings_taken = false;  // true/false: whether PPD readings have been taken

uint16_t  g_pm1p0_sp_value      = 0;  // Standard Particle calibration pm1.0 reading
uint16_t  g_pm2p5_sp_value      = 0;  // Standard Particle calibration pm2.5 reading
uint16_t  g_pm10p0_sp_value     = 0;  // Standard Particle calibration pm10.0 reading

uint16_t  g_pm1p0_ae_value      = 0;  // Atmospheric Environment pm1.0 reading
uint16_t  g_pm2p5_ae_value      = 0;  // Atmospheric Environment pm2.5 reading
uint16_t  g_pm10p0_ae_value     = 0;  // Atmospheric Environment pm10.0 reading

uint32_t  g_pm0p3_ppd_value     = 0;  // Particles Per Deciliter pm0.3 reading
uint32_t  g_pm0p5_ppd_value     = 0;  // Particles Per Deciliter pm0.5 reading
uint32_t  g_pm1p0_ppd_value     = 0;  // Particles Per Deciliter pm1.0 reading
uint32_t  g_pm2p5_ppd_value     = 0;  // Particles Per Deciliter pm2.5 reading
uint32_t  g_pm5p0_ppd_value     = 0;  // Particles Per Deciliter pm5.0 reading
uint32_t  g_pm10p0_ppd_value    = 0;  // Particles Per Deciliter pm10.0 reading

uint8_t   g_uk_aqi_value        = 0;  // Air Quality Index value using UK reporting system
uint16_t  g_us_aqi_value        = 0;  // Air Quality Index value using US reporting system

// MQTT
char g_mqtt_message_buffer[255];      // General purpose buffer for MQTT messages
char g_command_topic[50];             // MQTT topic for receiving commands

#if REPORT_MQTT_SEPARATE
char g_pm1p0_ae_mqtt_topic[50];       // MQTT topic for reporting pm1.0 AE value
char g_pm2p5_ae_mqtt_topic[50];       // MQTT topic for reporting pm2.5 AE value
char g_pm10p0_ae_mqtt_topic[50];      // MQTT topic for reporting pm10.0 AE value
char g_pm0p3_ppd_mqtt_topic[50];      // MQTT topic for reporting pm0.3 PPD value
char g_pm0p5_ppd_mqtt_topic[50];      // MQTT topic for reporting pm0.5 PPD value
char g_pm1p0_ppd_mqtt_topic[50];      // MQTT topic for reporting pm1.0 PPD value
char g_pm2p5_ppd_mqtt_topic[50];      // MQTT topic for reporting pm2.5 PPD value
char g_pm5p0_ppd_mqtt_topic[50];      // MQTT topic for reporting pm5.0 PPD value
char g_pm10p0_ppd_mqtt_topic[50];     // MQTT topic for reporting pm10.0 PPD value
char g_uk_aqi_mqtt_topic[50];         // MQTT topic for UK-format AQI value
char g_us_aqi_mqtt_topic[50];         // MQTT topic for US-format AQI value
#endif
#if REPORT_MQTT_JSON
char g_mqtt_json_topic[50];           // MQTT topic for reporting all values using JSON
#endif

// OLED Display
#define DISPLAY_STATE_GRAMS   1       // Display values in micrograms/m^3 on screen
#define DISPLAY_STATE_PPD     2       // Display values in parts per deciliter on screen
#define DISPLAY_STATE_INFO    3       // Display network status on screen
#define NUM_OF_STATES 3               // Number of possible states
uint8_t g_display_state = DISPLAY_STATE_GRAMS;  // Display values in micrograms/m^3 by default

// Mode Button
uint8_t  g_current_mode_button_state  =  1;  // Pin is pulled high by default
uint8_t  g_previous_mode_button_state =  1;
uint32_t g_last_debounce_time         =  0;
uint32_t g_debounce_delay             = 100;

// Wifi
#define WIFI_CONNECT_INTERVAL           500  // Wait 500ms intervals for wifi connection
#define WIFI_CONNECT_MAX_ATTEMPTS        10  // Number of attempts/intervals to wait

// General
uint32_t g_device_id;                    // Unique ID from ESP chip ID
uint32_t g_device_id2;                    // Unique ID from ESP chip ID

/*--------------------------- Function Signatures ------------------------*/
void mqttCallback(char* topic, byte* payload, uint8_t length);
void checkModeButton();
bool initWifi();
void reconnectMqtt();
void updatePmsReadings();
void reportToMqtt();
void renderScreen();

/* -------------------------- Resources ----------------------------------*/
#include "aqi.h"                         // Air Quality Index calculations

/*--------------------------- Instantiate Global Objects -----------------*/
// Software serial port
SoftwareSerial pmsSerial(PMS_RX_PIN, PMS_TX_PIN); // Rx pin = GPIO2 (D4 on Wemos D1 Mini)

// Particulate matter sensor
PMS pms(pmsSerial);                      // Use the software serial port for the PMS
PMS::DATA g_data;

// OLED
Adafruit_SSD1306 OLED(SCREEN_WIDTH, SCREEN_HEIGHT, &Wire, OLED_RESET);

// MQTT
WiFiClient esp_client;
PubSubClient client(esp_client);

/*--------------------------- Program ------------------------------------*/
/**
  Setup
*/
void setup()
{
  Serial.begin(SERIAL_BAUD_RATE);   // GPIO1, GPIO3 (TX/RX pin on ESP-12E Development Board)
  Serial.println();
  Serial.print("Air Quality Sensor starting up, v");
  Serial.println(VERSION);

  // Open a connection to the PMS and put it into passive mode
  pmsSerial.begin(PMS_BAUD_RATE);   // Connection for PMS5003
  pms.passiveMode();                // Tell PMS to stop sending data automatically
  delay(100);
  pms.wakeUp();                     // Tell PMS to wake up (turn on fan and laser)

  // We need a unique device ID for our MQTT client connection
  g_device_id = ESP.getChipId();  // Get the unique ID of the ESP8266 chip
  Serial.print("Device ID: ");
  Serial.println(g_device_id, HEX);

  // Set up display
  OLED.begin();
  OLED.clearDisplay();
  OLED.setTextWrap(false);
  OLED.setTextSize(1);
  OLED.setTextColor(WHITE);
  OLED.setCursor(0, 0);
  OLED.println("www.superhouse.tv/aqs");
  OLED.println(" Particulate Matter");
  OLED.print(" Sensor v"); OLED.println(VERSION);
  OLED.print  (" Device id: ");
  OLED.println(g_device_id, HEX);
  OLED.display();

  // Set up the topics for publishing sensor readings. By inserting the unique ID,
  // the result is of the form: "tele/d9616f/AE1P0" etc
  sprintf(g_command_topic,         "cmnd/%x/COMMAND",   ESP.getChipId());  // For receiving commands
#if REPORT_MQTT_SEPARATE
  sprintf(g_pm1p0_ae_mqtt_topic,   "tele/%x/AE1P0",     ESP.getChipId());  // Data from PMS
  sprintf(g_pm2p5_ae_mqtt_topic,   "tele/%x/AE2P5",     ESP.getChipId());  // Data from PMS
  sprintf(g_pm10p0_ae_mqtt_topic,  "tele/%x/AE10P0",    ESP.getChipId());  // Data from PMS
  sprintf(g_pm0p3_ppd_mqtt_topic,  "tele/%x/PPD0P3",    ESP.getChipId());  // Data from PMS
  sprintf(g_pm0p5_ppd_mqtt_topic,  "tele/%x/PPD0P5",    ESP.getChipId());  // Data from PMS
  sprintf(g_pm1p0_ppd_mqtt_topic,  "tele/%x/PPD1P0",    ESP.getChipId());  // Data from PMS
  sprintf(g_pm2p5_ppd_mqtt_topic,  "tele/%x/PPD2P5",    ESP.getChipId());  // Data from PMS
  sprintf(g_pm5p0_ppd_mqtt_topic,  "tele/%x/PPD5P0",    ESP.getChipId());  // Data from PMS
  sprintf(g_pm10p0_ppd_mqtt_topic, "tele/%x/PPD10P0",   ESP.getChipId());  // Data from PMS
  sprintf(g_uk_aqi_mqtt_topic,     "tele/%x/AQIUK",     ESP.getChipId());  // Calculated value
  sprintf(g_us_aqi_mqtt_topic,     "tele/%x/AQIUS",     ESP.getChipId());  // Calculated value
#endif
#if REPORT_MQTT_JSON
  sprintf(g_mqtt_json_topic,       "tele/%x/SENSOR",    ESP.getChipId());  // Data from PMS
#endif

  // Report the MQTT topics to the serial console
  Serial.println(g_command_topic);          // For receiving messages
#if REPORT_MQTT_SEPARATE
  Serial.println("MQTT topics:");
  Serial.println(g_pm1p0_ae_mqtt_topic);    // From PMS
  Serial.println(g_pm2p5_ae_mqtt_topic);    // From PMS
  Serial.println(g_pm10p0_ae_mqtt_topic);   // From PMS
  Serial.println(g_pm0p3_ppd_mqtt_topic);   // From PMS
  Serial.println(g_pm0p5_ppd_mqtt_topic);   // From PMS
  Serial.println(g_pm1p0_ppd_mqtt_topic);   // From PMS
  Serial.println(g_pm2p5_ppd_mqtt_topic);   // From PMS
  Serial.println(g_pm5p0_ppd_mqtt_topic);   // From PMS
  Serial.println(g_pm10p0_ppd_mqtt_topic);  // From PMS
  Serial.println(g_uk_aqi_mqtt_topic);      // Calculated value
  Serial.println(g_us_aqi_mqtt_topic);      // Calculated value
#endif
#if REPORT_MQTT_JSON
  Serial.println(g_mqtt_json_topic);        // From PMS
#endif

  // Connect to WiFi
  Serial.println("Connecting to WiFi");
  if (initWifi())
  {
    OLED.println("WiFi [CONNECTED]");
    Serial.println("WiFi connected");
  } else {
    OLED.println("WiFi [FAILED]");
    Serial.println("WiFi FAILED");
  }
  OLED.display();
  delay(100);

  pinMode(MODE_BUTTON_PIN, INPUT_PULLUP); // Pin for screen mode button

  /* Set up the MQTT client */
  client.setServer(mqtt_broker, 1883);
  client.setCallback(mqttCallback);
  client.setBufferSize(255);
}

/**
  Main loop
*/
void loop()
{
  if (WiFi.status() == WL_CONNECTED)
  {
    if (!client.connected())
    {
      reconnectMqtt();
    }
  }
  client.loop();  // Process any outstanding MQTT messages

  checkModeButton();
  updatePmsReadings();
  renderScreen();
}

/**
  Read the display mode button and switch the display mode if necessary
*/
void checkModeButton()
{
  g_current_mode_button_state = digitalRead(MODE_BUTTON_PIN);

  // Check if button is now pressed and it was previously unpressed
  if (HIGH == g_previous_mode_button_state && LOW == g_current_mode_button_state)
  {
    // We haven't waited long enough so ignore this press
    if (millis() - g_last_debounce_time <= g_debounce_delay)
    {
      return;
    }
    Serial.println("Button pressed");

    // Increment display state
    g_last_debounce_time = millis();
    if (g_display_state >= NUM_OF_STATES)
    {
      g_display_state = 1;
    } else {
      g_display_state++;
    }
  }

  g_previous_mode_button_state = g_current_mode_button_state;
}

/**
  Update particulate matter sensor values
*/
void updatePmsReadings()
{
  uint32_t time_now = millis();

  // Check if we've been in the sleep state for long enough
  if (PMS_STATE_ASLEEP == g_pms_state)
  {
    if (time_now - g_pms_state_start
        >= ((g_pms_report_period * 1000) - (g_pms_warmup_period * 1000)))
    {
      // It's time to wake up the sensor
      //Serial.println("Waking up sensor");
      pms.wakeUp();
      g_pms_state_start = time_now;
      g_pms_state = PMS_STATE_WAKING_UP;
    }
  }

  // Check if we've been in the waking up state for long enough
  if (PMS_STATE_WAKING_UP == g_pms_state)
  {
    if (time_now - g_pms_state_start
        >= (g_pms_warmup_period * 1000))
    {
      g_pms_state_start = time_now;
      g_pms_state = PMS_STATE_READY;
    }
  }

  // Put the most recent values into globals for reference elsewhere
  if (PMS_STATE_READY == g_pms_state)
  {
    //pms.requestRead();
    if (pms.readUntil(g_data))  // Use a blocking road to make sure we get values
    {
      g_pm1p0_sp_value   = g_data.PM_SP_UG_1_0;
      g_pm2p5_sp_value   = g_data.PM_SP_UG_2_5;
      g_pm10p0_sp_value  = g_data.PM_SP_UG_10_0;

      g_pm1p0_ae_value   = g_data.PM_AE_UG_1_0;
      g_pm2p5_ae_value   = g_data.PM_AE_UG_2_5;
      g_pm10p0_ae_value  = g_data.PM_AE_UG_10_0;

      g_pms_ae_readings_taken = true;

      // This condition below should NOT be required, but currently I get all
      // 0 values for the PPD results every second time. This check only updates
      // the global values if there is a non-zero result for any of the values:
      if (g_data.PM_TOTALPARTICLES_0_3 + g_data.PM_TOTALPARTICLES_0_5
          + g_data.PM_TOTALPARTICLES_1_0 + g_data.PM_TOTALPARTICLES_2_5
          + g_data.PM_TOTALPARTICLES_5_0 + g_data.PM_TOTALPARTICLES_10_0
          != 0)
      {
        g_pm0p3_ppd_value  = g_data.PM_TOTALPARTICLES_0_3;
        g_pm0p5_ppd_value  = g_data.PM_TOTALPARTICLES_0_5;
        g_pm1p0_ppd_value  = g_data.PM_TOTALPARTICLES_1_0;
        g_pm2p5_ppd_value  = g_data.PM_TOTALPARTICLES_2_5;
        g_pm5p0_ppd_value  = g_data.PM_TOTALPARTICLES_5_0;
        g_pm10p0_ppd_value = g_data.PM_TOTALPARTICLES_10_0;
        g_pms_ppd_readings_taken = true;
      }
      pms.sleep();

      // Calculate AQI values for the various reporting standards
      calculateUkAqi();

      // Report the new values
      reportToMqtt();
      reportToSerial();

      g_pms_state_start = time_now;
      g_pms_state = PMS_STATE_ASLEEP;
    }
  }
}

/**
  Render the correct screen based on the display mode
*/
void renderScreen()
{
  OLED.clearDisplay();
  OLED.setCursor(0, 0);

  // Render our displays
  switch (g_display_state)
  {
    case DISPLAY_STATE_GRAMS:
      OLED.setTextWrap(false);

      if (true == g_pms_ae_readings_taken)
      {
        OLED.println("  Particles ug/m^3");

        OLED.print("     PM  1.0: ");
        OLED.println(g_pm1p0_ae_value);

        OLED.print("     PM  2.5: ");
        OLED.println(g_pm2p5_ae_value);

        OLED.print("     PM 10.0: ");
        OLED.println(g_pm10p0_ae_value);
      } else {
        OLED.println("  Particles ug/m^3");
        OLED.println("  ----------------");
        OLED.println(" Preparing sensor and");
        OLED.println("   waiting for data");
      }
      break;

    case DISPLAY_STATE_PPD:
      OLED.setTextWrap(false);

      if (true == g_pms_ppd_readings_taken)
      {
        OLED.println("Particles / Deciliter");

        OLED.print(" 0.3: ");
        OLED.print(g_pm0p3_ppd_value);
        OLED.setCursor(64, 8);
        OLED.print("0.5:  ");
        OLED.println(g_pm0p5_ppd_value);

        OLED.print(" 1.0: ");
        OLED.print(g_pm1p0_ppd_value);
        OLED.setCursor(64, 16);
        OLED.print("2.5:  ");
        OLED.println(g_pm2p5_ppd_value);

        OLED.print(" 5.0: ");
        OLED.print(g_pm5p0_ppd_value);
        OLED.setCursor(64, 24);
        OLED.print("10.0: ");
        OLED.println(g_pm10p0_ppd_value);
      } else {
        OLED.println("Particles / Deciliter");
        OLED.println("---------------------");
        OLED.println(" Preparing sensor and");
        OLED.println("   waiting for data");
      }
      break;

    case DISPLAY_STATE_INFO:
      OLED.print("IP:   ");
      OLED.println(WiFi.localIP());
      char mqtt_client_id[20];
      sprintf(mqtt_client_id, "esp8266%x", g_device_id);
      OLED.setTextWrap(false);
      OLED.print("ID:   ");
      OLED.println(mqtt_client_id);
      OLED.print("SSID: ");
      OLED.println(ssid);
      OLED.print("WiFi: ");
      if (WiFi.status() == WL_CONNECTED)
      {
        OLED.print("OK");
      } else {
        OLED.print("FAILED");
      }
      OLED.print("   Up:");
      OLED.print((int)millis() / 1000);
      break;

    /* This fallback helps with debugging if you call a state that isn't defined */
    default:
      OLED.println("Unknown state:");
      OLED.println(g_display_state);
      break;
  }

  OLED.display();
}

/**
  Report the latest values to MQTT
*/
void reportToMqtt()
{
  String message_string;

#if REPORT_MQTT_SEPARATE
  if (true == g_pms_ae_readings_taken)
  {
    /* Report PM1.0 AE value */
    message_string = String(g_pm1p0_ae_value);
    message_string.toCharArray(g_mqtt_message_buffer, message_string.length() + 1);
    client.publish(g_pm1p0_ae_mqtt_topic, g_mqtt_message_buffer);

    /* Report PM2.5 AE value */
    message_string = String(g_pm2p5_ae_value);
    message_string.toCharArray(g_mqtt_message_buffer, message_string.length() + 1);
    client.publish(g_pm2p5_ae_mqtt_topic, g_mqtt_message_buffer);

    /* Report PM10.0 AE value */
    message_string = String(g_pm10p0_ae_value);
    message_string.toCharArray(g_mqtt_message_buffer, message_string.length() + 1);
    client.publish(g_pm10p0_ae_mqtt_topic, g_mqtt_message_buffer);
  }

  if (true == g_pms_ppd_readings_taken)
  {
    /* Report PM0.3 PPD value */
    message_string = String(g_pm0p3_ppd_value);
    message_string.toCharArray(g_mqtt_message_buffer, message_string.length() + 1);
    client.publish(g_pm0p3_ppd_mqtt_topic, g_mqtt_message_buffer);

    /* Report PM0.5 PPD value */
    message_string = String(g_pm0p5_ppd_value);
    message_string.toCharArray(g_mqtt_message_buffer, message_string.length() + 1);
    client.publish(g_pm0p5_ppd_mqtt_topic, g_mqtt_message_buffer);

    /* Report PM1.0 PPD value */
    message_string = String(g_pm1p0_ppd_value);
    message_string.toCharArray(g_mqtt_message_buffer, message_string.length() + 1);
    client.publish(g_pm1p0_ppd_mqtt_topic, g_mqtt_message_buffer);

    /* Report PM2.5 PPD value */
    message_string = String(g_pm2p5_ppd_value);
    message_string.toCharArray(g_mqtt_message_buffer, message_string.length() + 1);
    client.publish(g_pm2p5_ppd_mqtt_topic, g_mqtt_message_buffer);

    /* Report PM5.0 PPD value */
    message_string = String(g_pm5p0_ppd_value);
    message_string.toCharArray(g_mqtt_message_buffer, message_string.length() + 1);
    client.publish(g_pm5p0_ppd_mqtt_topic, g_mqtt_message_buffer);

    /* Report PM10.0 PPD value */
    message_string = String(g_pm10p0_ppd_value);
    message_string.toCharArray(g_mqtt_message_buffer, message_string.length() + 1);
    client.publish(g_pm10p0_ppd_mqtt_topic, g_mqtt_message_buffer);

    /* Report UK AQI value */
    message_string = String(g_uk_aqi_value);
    message_string.toCharArray(g_mqtt_message_buffer, message_string.length() + 1);
    client.publish(g_uk_aqi_mqtt_topic, g_mqtt_message_buffer);
  }
#endif

#if REPORT_MQTT_JSON
  /* Report all values combined into one JSON message */
  // This is an example message generated by Tasmota, to match the format:
  // {"Time":"2020-02-27T03:27:22","PMS5003":{"CF1":0,"CF2.5":1,"CF10":1,"PM1":0,"PM2.5":1,"PM10":1,"PB0.3":0,"PB0.5":0,"PB1":0,"PB2.5":0,"PB5":0,"PB10":0}}
  // This is the source code from Tasmota:
  //ResponseAppend_P(PSTR(",\"PMS5003\":{\"CF1\":%d,\"CF2.5\":%d,\"CF10\":%d,\"PM1\":%d,\"PM2.5\":%d,\"PM10\":%d,\"PB0.3\":%d,\"PB0.5\":%d,\"PB1\":%d,\"PB2.5\":%d,\"PB5\":%d,\"PB10\":%d}"),
  //    pms_g_data.pm10_standard, pms_data.pm25_standard, pms_data.pm100_standard,
  //    pms_data.pm10_env, pms_data.pm25_env, pms_data.pm100_env,
  //    pms_data.particles_03um, pms_data.particles_05um, pms_data.particles_10um, pms_data.particles_25um, pms_data.particles_50um, pms_data.particles_100um);

  // Note: The PubSubClient library limits MQTT message size to 128 bytes. The long format
  // message below only works because the message buffer size has been increased to 255 bytes
  // in setup.

  // Format the message as JSON in the outgoing message buffer:
  if (true == g_pms_ppd_readings_taken)
  {
    sprintf(g_mqtt_message_buffer,  "{\"PMS5003\":{\"CF1\":%i,\"CF2.5\":%i,\"CF10\":%i,\"PM1\":%i,\"PM2.5\":%i,\"PM10\":%i,\"PB0.3\":%i,\"PB0.5\":%i,\"PB1\":%i,\"PB2.5\":%i,\"PB5\":%i,\"PB10\":%i,\"UKAQI\":%i}}",
            g_pm1p0_sp_value, g_pm2p5_sp_value, g_pm10p0_sp_value,
            g_pm1p0_ae_value, g_pm2p5_ae_value, g_pm10p0_ae_value,
            g_pm0p3_ppd_value, g_pm0p5_ppd_value, g_pm1p0_ppd_value,
            g_pm2p5_ppd_value, g_pm5p0_ppd_value, g_pm10p0_ppd_value,
            g_uk_aqi_value);
  } else {
    sprintf(g_mqtt_message_buffer,  "{\"PMS5003\":{\"CF1\":%i,\"CF2.5\":%i,\"CF10\":%i,\"PM1\":%i,\"PM2.5\":%i,\"PM10\":%i}}",
            g_pm1p0_sp_value, g_pm2p5_sp_value, g_pm10p0_sp_value,
            g_pm1p0_ae_value, g_pm2p5_ae_value, g_pm10p0_ae_value);
  }

  client.publish(g_mqtt_json_topic, g_mqtt_message_buffer);
#endif
}
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

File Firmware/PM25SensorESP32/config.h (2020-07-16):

/* ----------------- General Config -------------------------------- */
/* WiFi config */
const char* ssid                  = "YOUR SSID";     // Your WiFi SSID
const char* password              = "YOUR PASS";     // Your WiFi password

/* MQTT */
const char* mqtt_broker           = "192.168.1.111"; // IP address of your MQTT broker
#define     REPORT_MQTT_SEPARATE  true               // Report each value to its own topic
#define     REPORT_MQTT_JSON      true               // Report all values in a JSON message
const char* status_topic          = "events";        // MQTT topic to report startup

/* Particulate Matter Sensor */
uint32_t    g_pms_warmup_period   =  30;             // Seconds to warm up PMS before reading
uint32_t    g_pms_report_period   = 120;             // Seconds between reports

/* Use WiFi. If this is off, MQTT won't run */
#define ENABLE_WIFI       true

/* Serial */
#define     SERIAL_BAUD_RATE       9600              // Speed for USB serial console

/* Environmental sensor */
#define SEA_LEVEL_PRESSURE_HPA (1013.25)

/* ----------------- Hardware-specific Config ---------------------- */
/* Mode button connection (momentary between this pin and GND) */
#define MODE_BUTTON_PIN    0

/* RGB LEDs */
#define WS2812B_PIN       13
#define NUM_RGB_LEDS       2

/* LCD */
#define TFT_DC_PIN         2
#define TFT_RST_PIN        4
#define TFT_CS_PIN        26
#define TFT_SCLK_PIN      18
#define TFT_MISO_PIN      19
#define TFT_MOSI_PIN      23

/* I2C */
#define I2C_SDA_PIN       21
#define I2C_SCL_PIN       22
#define BME680_I2C_ADDR 0x76

/* Particulate Matter Sensor */
#define PMS_BAUD_RATE   9600
#define PMS_SET_PIN       25
#define PMS_RESET_PIN     27
#define PMS_RX_PIN        17 //  Tx to the PMS SHOULD BE 16
#define PMS_TX_PIN        16 //  Rx from the PMS SHOULD BE 17

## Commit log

2020-02-09 Initial import
    [AQS.brd, AQS.sch]
2020-02-10 Major update to use 240x240 SPI LCD
    [AQS.brd, AQS.sch]
2020-02-14 Fixed button pin config
    [config.h]
2020-02-14 Convert to ESP32, add LCD support, add SuperHouse logo, add serial port for PMS7003
2020-02-17 Changed TX pin to PMS7003
2020-03-04 Added I2C address for BME680. Changed name of reporting period option to match Tasmota convention. Added sea level pressure value for altitude calculations.
2020-03-04 Changed MQTT topic names to match Tasmota conventions. Major improvements to TFT screen formatting. Made sensor updates asynchronous to decouple it from reporting methods.
2020-03-08 Moved mode button to GPIO0
    [AQS.brd, AQS.sch]
2020-04-30 Replaced CP2102N with CH340G; removed 2 LEDs; reworked routing; moved button
    [AQS.brd, AQS.sch]
2020-06-15 Replaced programming header
    [AQS.brd, AQS.sch]
2020-07-15 Routing for CP2102N
    [AQS.brd, AQS.sch]
2020-07-15 Restructuring in preparation for merging projects
    [AQS.brd, AQS.sch]
2020-07-16 Major restructure and changes to pin allocations
2020-07-17 Finished major rework for v3.0 release
    [AQS.brd, AQS.sch]
2020-08-09 Experiments with alternative layout putting all SMT parts behind the sensor to reduce size
    [AQS.brd, AQS.sch]
2021-04-22 Added design files for enclosures.
    [AQS-Basic-Case-1_2mm-v1-bottom.stl, AQS-Basic-Case-1_2mm-v1-top.stl, AQS-Basic-Case-1_6mm-v1-bottom.stl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]
2021-04-22 Added images of different versions and enclosures.
2021-06-03 Fix button logic
    Without the patch the display keeps switching the state fast until you release
    the button.
    [AirQualitySensorD1Mini.ino]
2021-09-26 Major restructure to reduce size of PCB. ERC and DRC for v3.0 release.
    [AQS.brd, AQS.sch]
2021-09-26 Removed extra board layers.
    [AQS.brd]
2024-01-15 Added STEP files.
    [AQS-Display-Case-v16.step, AQS-Simple-Case-v5.step]
2024-10-03 Updated hardware files for v4.0 release.
    [AQS-v4_0.brd, AQS-v4_0.sch]
2024-10-03 Deleted obsolete files.
    [AQS.brd, AQS.sch]

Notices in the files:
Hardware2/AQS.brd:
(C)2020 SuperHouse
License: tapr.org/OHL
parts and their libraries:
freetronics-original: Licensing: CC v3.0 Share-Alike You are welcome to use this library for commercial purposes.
